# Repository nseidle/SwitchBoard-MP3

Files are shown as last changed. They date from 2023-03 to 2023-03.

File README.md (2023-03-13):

Switchboard MP3 Player
=======

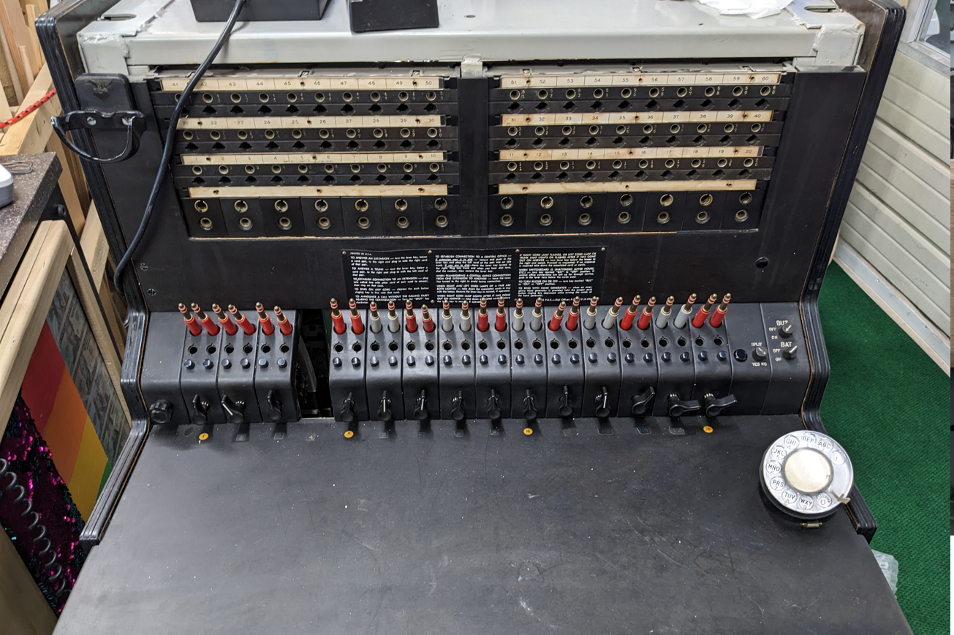
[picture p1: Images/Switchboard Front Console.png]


This project documents the modifications made to a vintage phone switchboard. This is an interactive exhibit at the WOW children's museum in Lafayette. Any of the audio plugs can be inserted into any of the ports in the top console. The light will turn on and one of 74 MP3s will play out the corded phone.

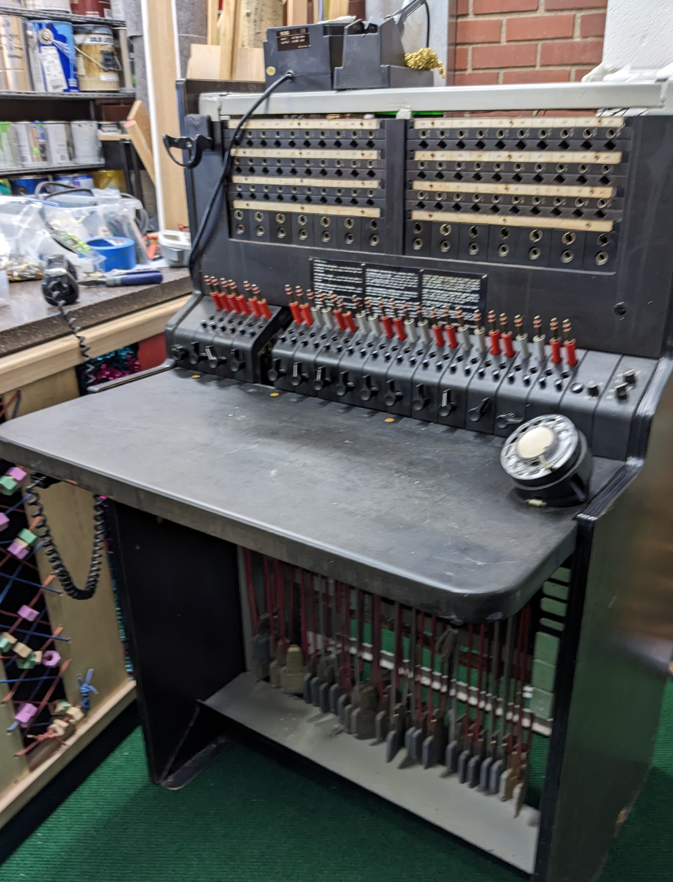
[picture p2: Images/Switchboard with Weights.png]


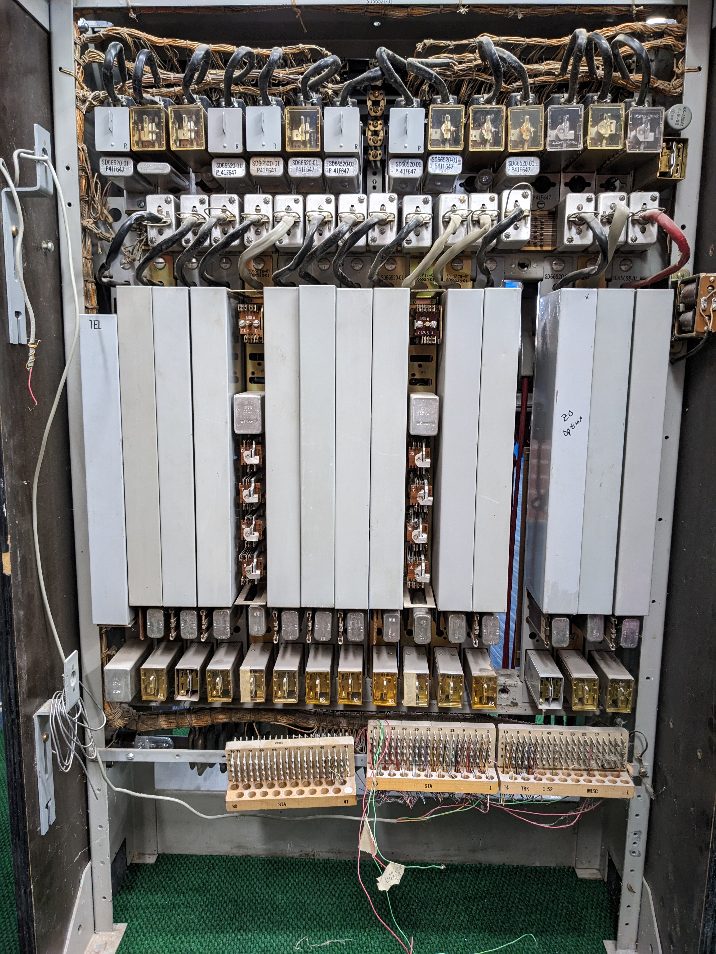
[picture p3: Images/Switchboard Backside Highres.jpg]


It was awesome to work on.

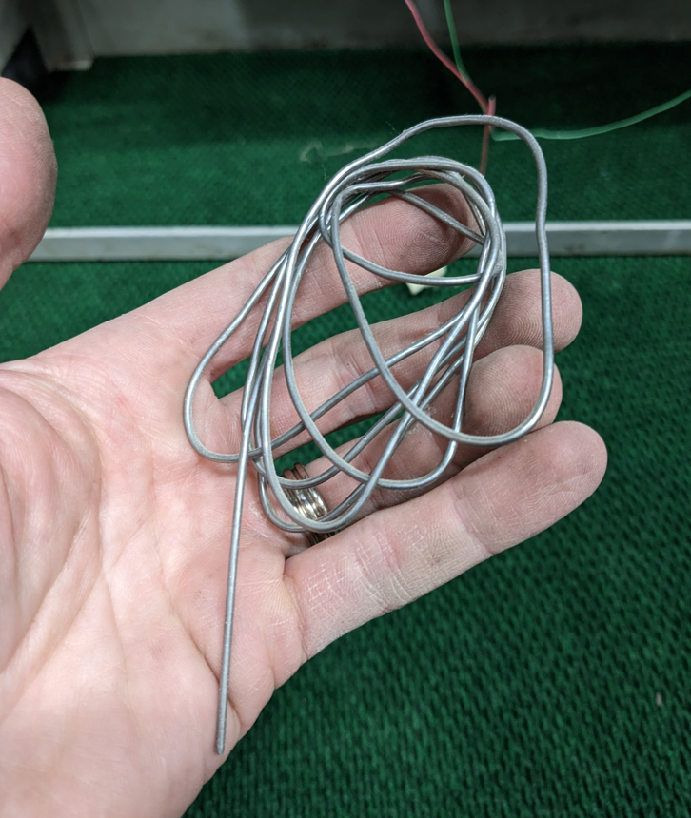
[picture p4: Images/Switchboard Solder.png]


I appreciate the switchboard contained its own solder. From 1956!

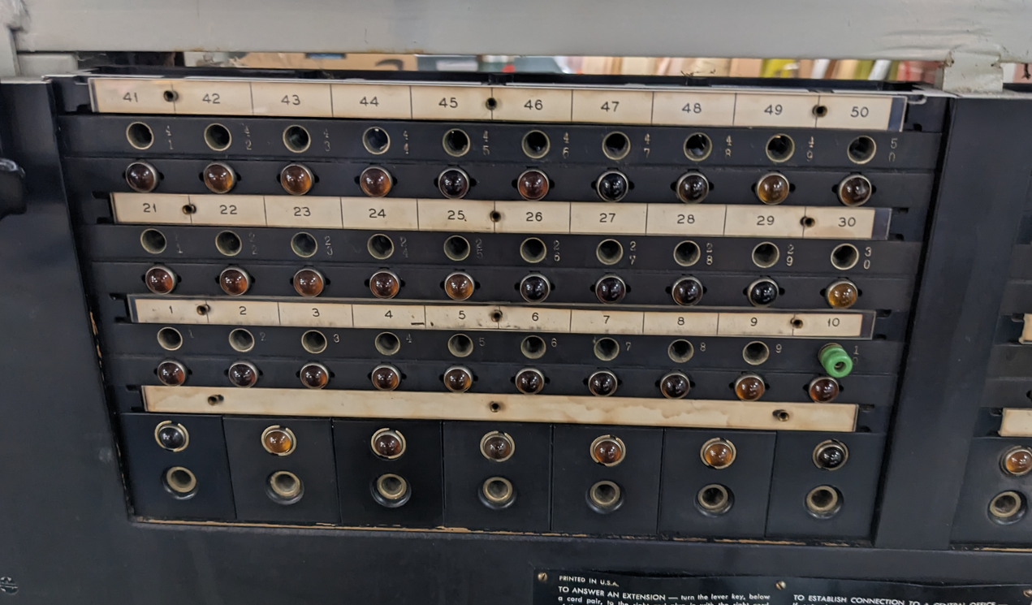
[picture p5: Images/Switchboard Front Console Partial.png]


Above, shows all the original glass lamp covers

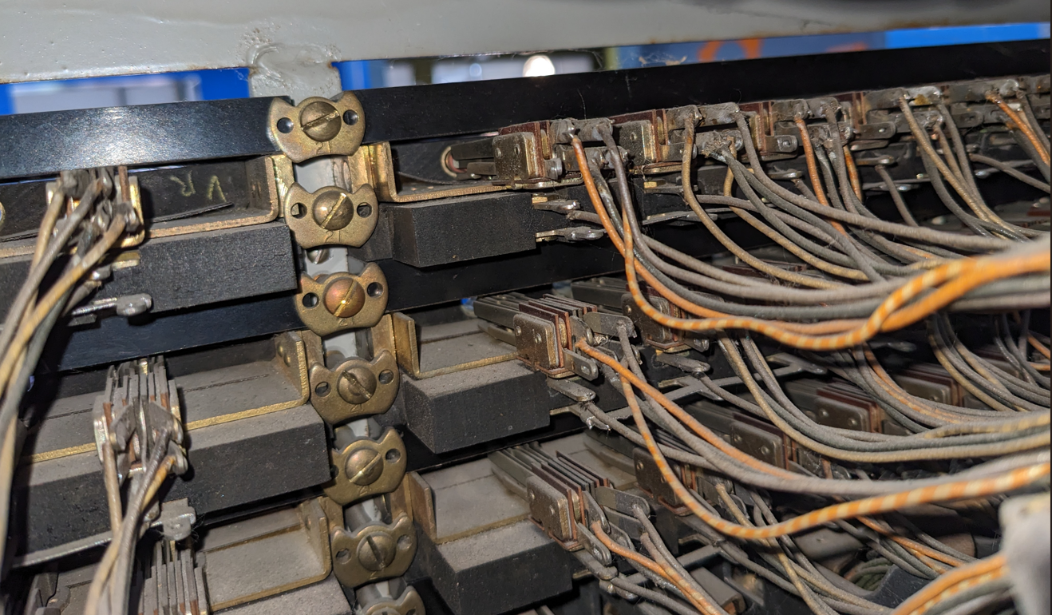
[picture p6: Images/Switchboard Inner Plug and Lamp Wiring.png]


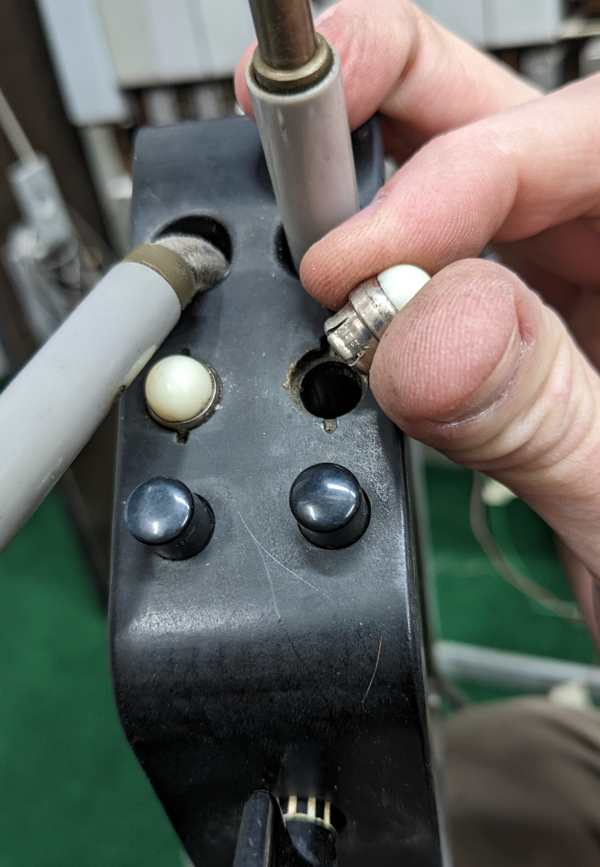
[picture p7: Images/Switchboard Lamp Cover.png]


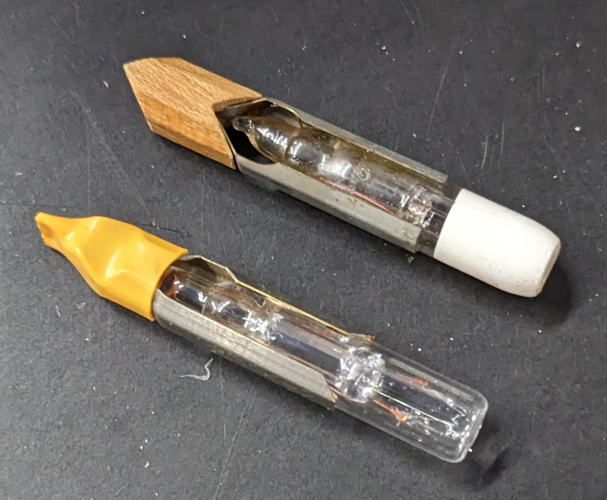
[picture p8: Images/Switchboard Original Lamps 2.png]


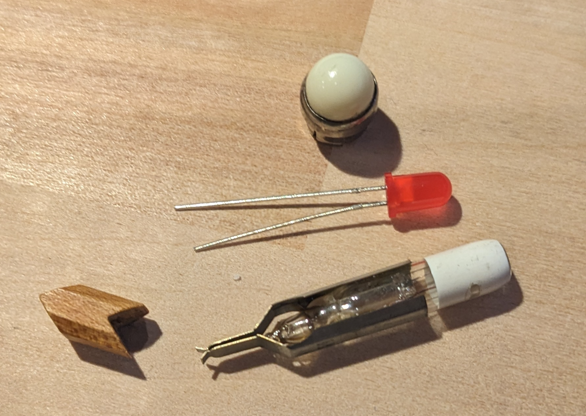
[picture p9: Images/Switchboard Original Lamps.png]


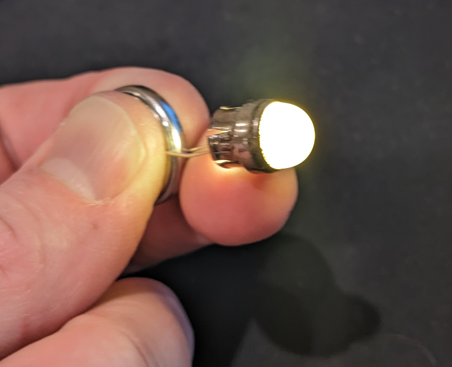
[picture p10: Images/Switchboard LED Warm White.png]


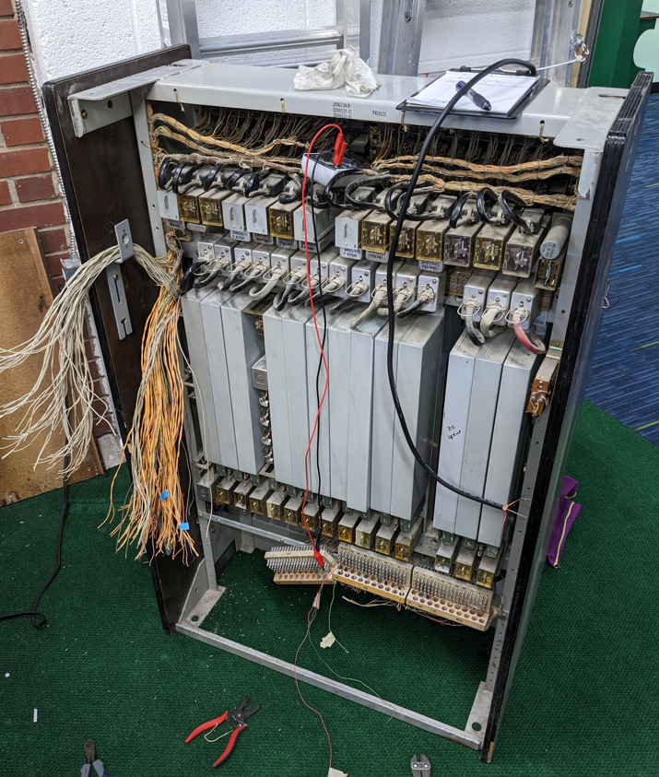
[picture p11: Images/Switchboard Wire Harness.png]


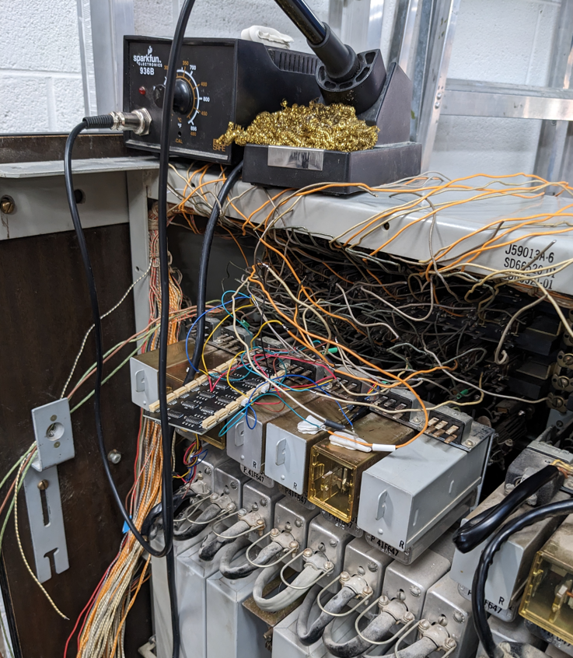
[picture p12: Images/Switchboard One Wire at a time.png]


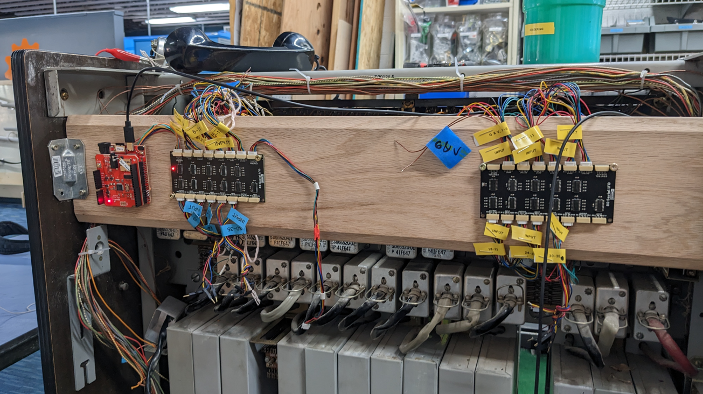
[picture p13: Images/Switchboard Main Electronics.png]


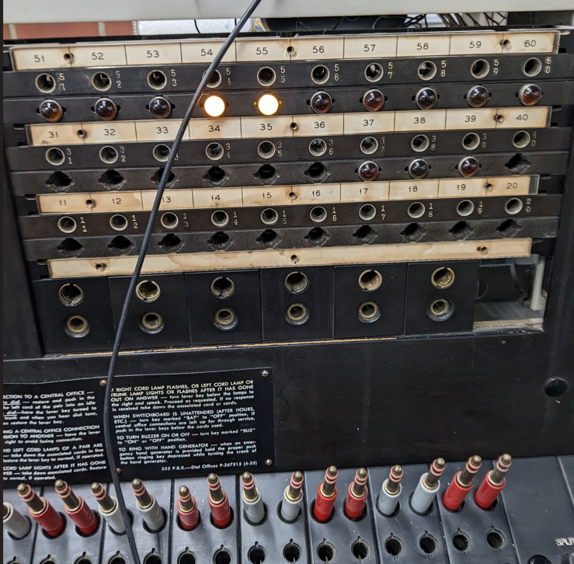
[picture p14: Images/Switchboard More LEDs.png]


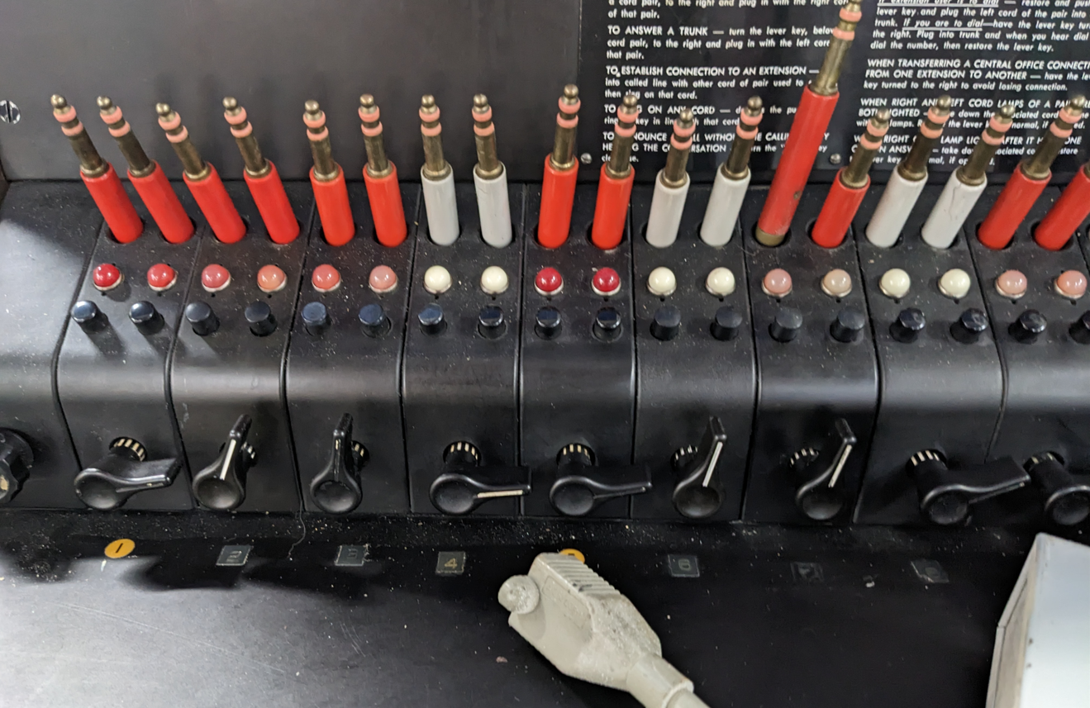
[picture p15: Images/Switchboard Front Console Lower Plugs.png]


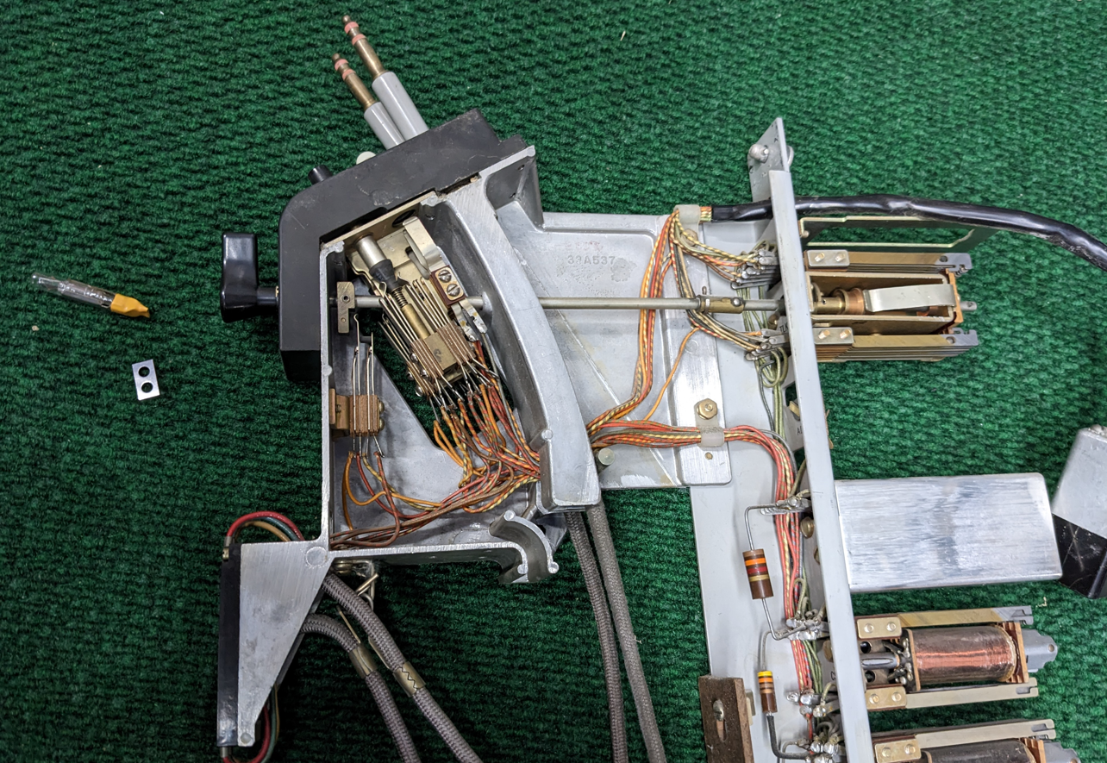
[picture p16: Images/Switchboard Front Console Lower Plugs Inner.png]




[Movie of LEDs](Images/Switchboard%20LEDs.mp4)

Repository Contents
-------------------

* **/firmware** - The code that runs on the ESP32.
* **/hardware** - A custom I/O board capable of 40 inputs and 40 outputs per board, with the ability to chain any number of boards together.

License Information
-------------------

This design is [OSHW](http://www.oshwa.org/definition/) and public domain but you buy me a beer if you use this and we meet someday ([Beerware license](http://en.wikipedia.org/wiki/Beerware)).

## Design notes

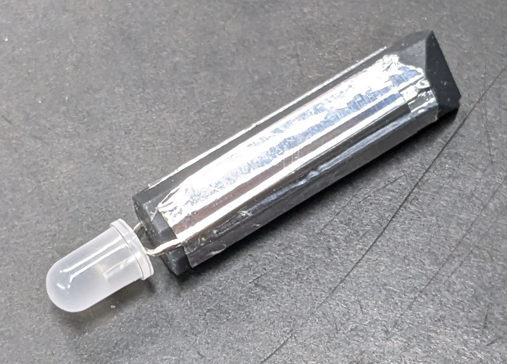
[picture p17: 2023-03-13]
Images/Switchboard LED Replacement.png

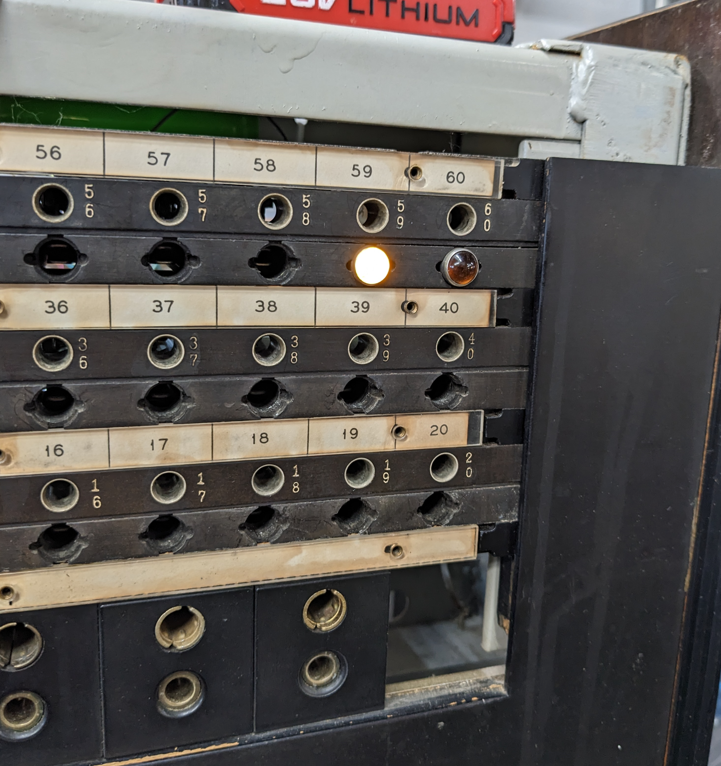
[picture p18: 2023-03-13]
Images/Switchboard Illuminated Light Caps.png

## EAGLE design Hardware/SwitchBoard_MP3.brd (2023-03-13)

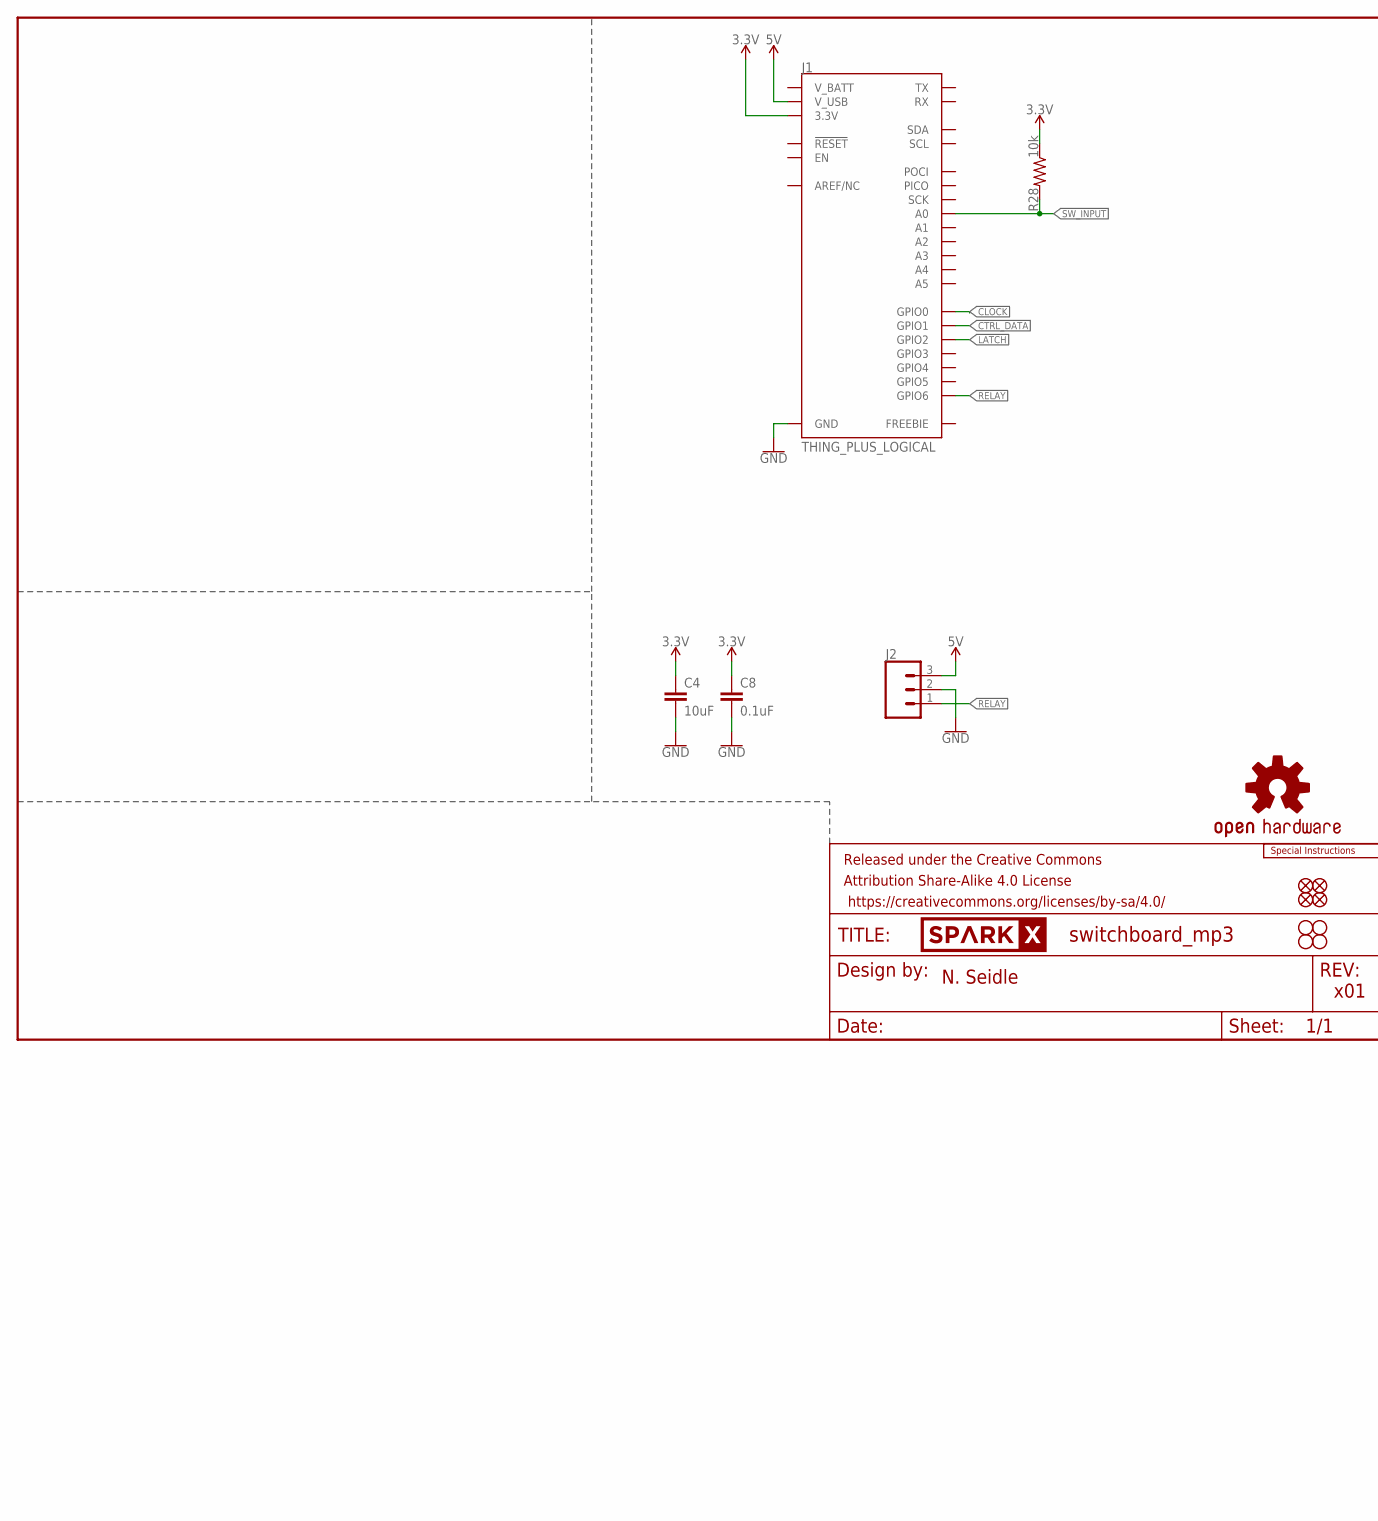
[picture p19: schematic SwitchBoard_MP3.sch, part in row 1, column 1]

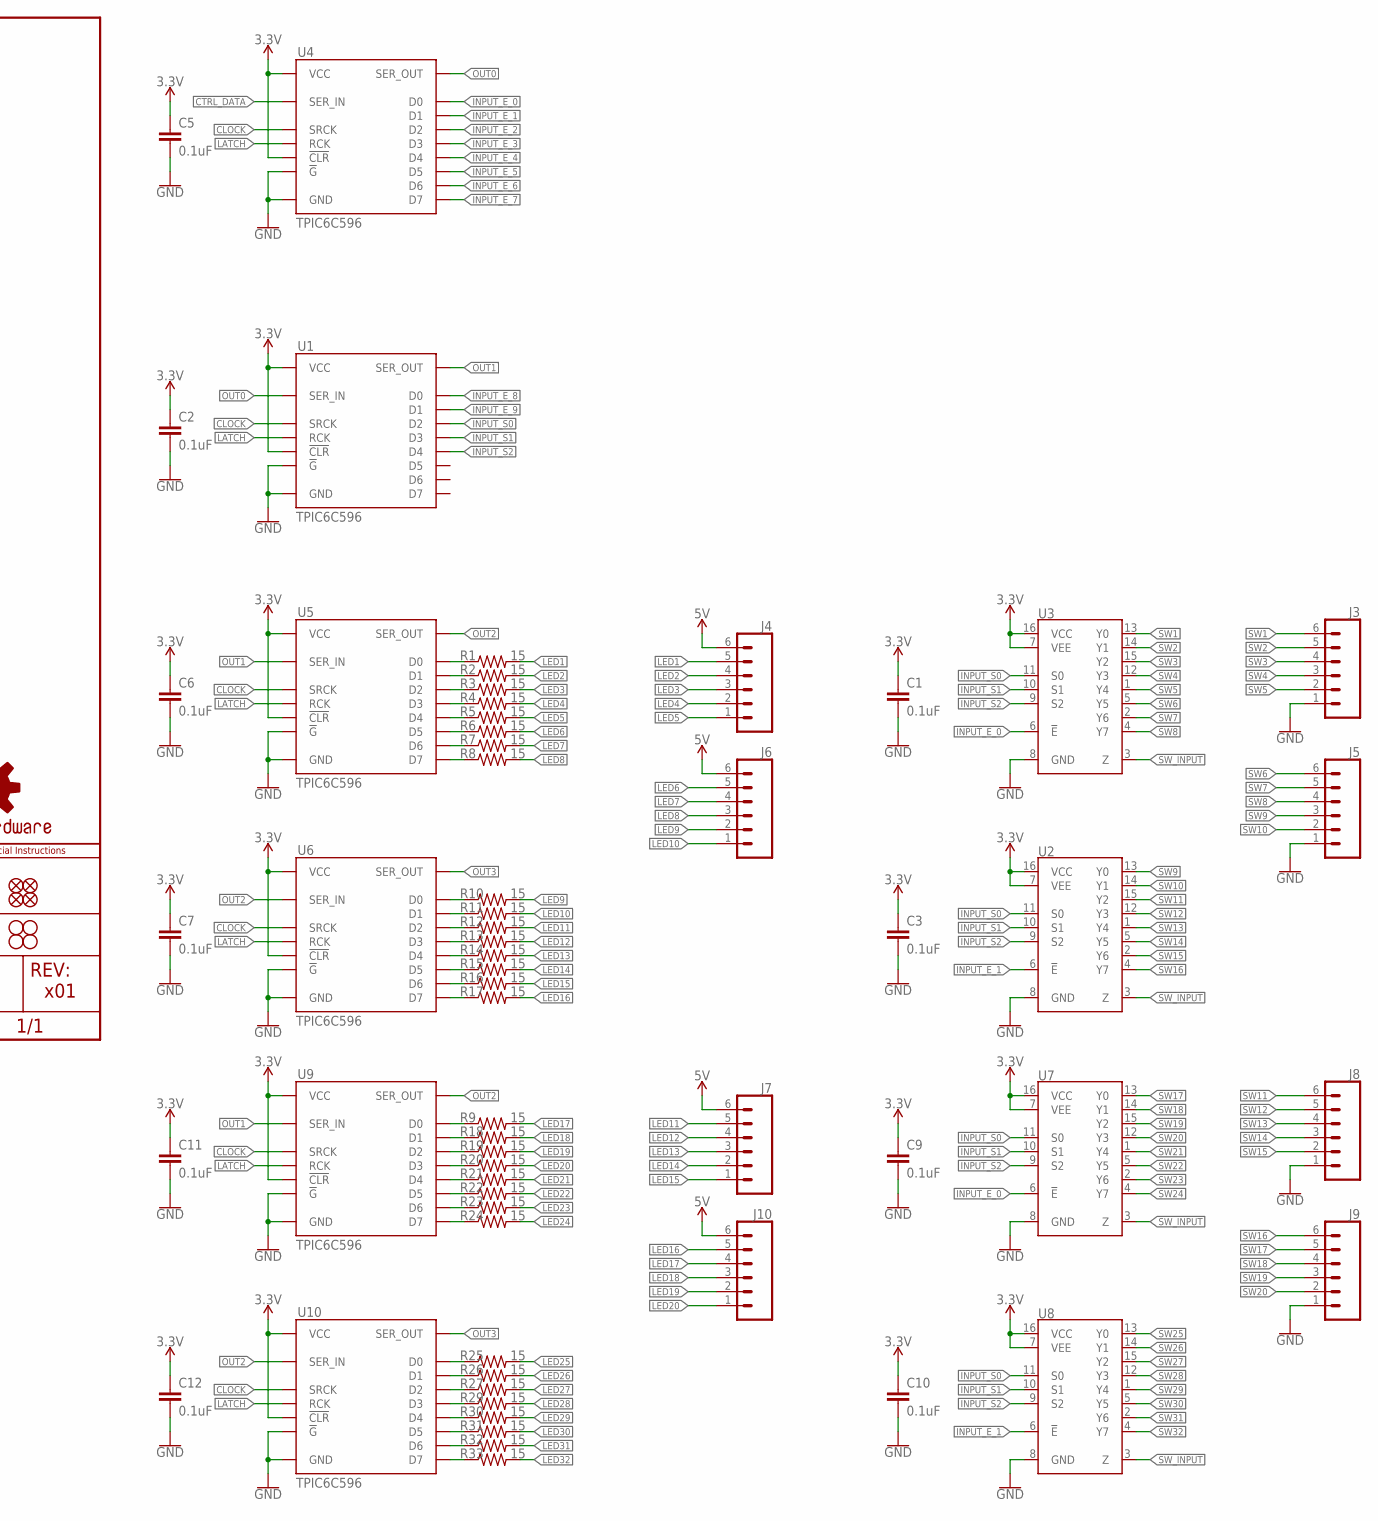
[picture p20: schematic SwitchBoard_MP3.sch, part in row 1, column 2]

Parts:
C1, C2, C3, C5, C6, C7, C8, C9, C10, C11, C12: 0.1uF; 0603
C4: 10uF; 0805
FD1, FD2, FD3, FD4: FIDUCIAL1X2; FIDUCIAL-1X2
FRAME1: FRAME-LETTER; CREATIVE_COMMONS
H1, H2, H3, H4: STAND-OFF
J1: THING_PLUS_LOGICAL; THING_PLUS
J2: CONN_03JST-PTH-NS; JST-3-PTH-NS
J3, J4, J5, J6, J7, J8, J9, J10: CONN_06JST-SMD-LOCKING; JST-6-SMD-1.25MM-LOCKING
LOGO1: SPECIAL_INSTRUCTIONS-ORDERING; ORDERING_INSTRUCTIONS
LOGO2: OSHW-LOGOS; OSHW-LOGO-S
R1, R2, R3, R4, R5, R6, R7, R8, R9, R10, R11, R12, R13, R14, R15, R16, R17, R18, R19, R20, R21, R22, R23, R24, R25, R26, R27, R29, R30, R31, R32, R33: 15; 0603
R28: 10k; 0603
U1, U4, U5, U6, U9, U10: TPIC6C596; SO016
U2, U3, U7, U8: 744051; SO16
U$1: SPARKX-LOGO4; SPARKX-MEDIUM

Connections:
3.3V: C1.1, C2.1, C3.1, C4.1, C5.1, C6.1, C7.1, C8.1, C9.1, C10.1, C11.1, C12.1, J1.27 (3.3V), R28.1, U1.1 (VCC), U1.7 (!CLR), U2.7 (VEE), U2.16 (VCC), U3.7 (VEE), U3.16 (VCC), U4.1 (VCC), U4.7 (!CLR), U5.1 (VCC), U5.7 (!CLR), U6.1 (VCC), U6.7 (!CLR), U7.7 (VEE), U7.16 (VCC), U8.7 (VEE), U8.16 (VCC), U9.1 (VCC), U9.7 (!CLR), U10.1 (VCC), U10.7 (!CLR)
5V: J1.10 (V_USB), J2.3, J4.6, J6.6, J7.6, J10.6
CLOCK: J1.9 (GPIO0), U1.15 (SRCK), U4.15 (SRCK), U5.15 (SRCK), U6.15 (SRCK), U9.15 (SRCK), U10.15 (SRCK)
CTRL_DATA: J1.8 (GPIO1), U4.2 (SER_IN)
GND: C1.2, C2.2, C3.2, C4.2, C5.2, C6.2, C7.2, C8.2, C9.2, C10.2, C11.2, C12.2, J1.25 (GND), J2.2, J3.1, J5.1, J8.1, J9.1, U1.8 (!G), U1.16 (GND), U2.8 (GND), U3.8 (GND), U4.8 (!G), U4.16 (GND), U5.8 (!G), U5.16 (GND), U6.8 (!G), U6.16 (GND), U7.8 (GND), U8.8 (GND), U9.8 (!G), U9.16 (GND), U10.8 (!G), U10.16 (GND)
INPUT_!E!_0: U3.6 (!E!), U4.3 (D0), U7.6 (!E!)
INPUT_!E!_1: U2.6 (!E!), U4.4 (D1), U8.6 (!E!)
INPUT_!E!_2: U4.5 (D2)
INPUT_!E!_3: U4.6 (D3)
INPUT_!E!_4: U4.11 (D4)
INPUT_!E!_5: U4.12 (D5)
INPUT_!E!_6: U4.13 (D6)
INPUT_!E!_7: U4.14 (D7)
INPUT_!E!_8: U1.3 (D0)
INPUT_!E!_9: U1.4 (D1)
INPUT_S0: U1.5 (D2), U2.11 (S0), U3.11 (S0), U7.11 (S0), U8.11 (S0)
INPUT_S1: U1.6 (D3), U2.10 (S1), U3.10 (S1), U7.10 (S1), U8.10 (S1)
INPUT_S2: U1.11 (D4), U2.9 (S2), U3.9 (S2), U7.9 (S2), U8.9 (S2)
LATCH: J1.7 (GPIO2), U1.10 (RCK), U4.10 (RCK), U5.10 (RCK), U6.10 (RCK), U9.10 (RCK), U10.10 (RCK)
LED1: J4.5, R1.2
LED2: J4.4, R2.2
LED3: J4.3, R3.2
LED4: J4.2, R4.2
LED5: J4.1, R5.2
LED6: J6.5, R6.2
LED7: J6.4, R7.2
LED8: J6.3, R8.2
LED9: J6.2, R10.2
LED10: J6.1, R11.2
LED11: J7.5, R12.2
LED12: J7.4, R13.2
LED13: J7.3, R14.2
LED14: J7.2, R15.2
LED15: J7.1, R16.2
LED16: J10.5, R17.2
LED17: J10.4, R9.2
LED18: J10.3, R18.2
LED19: J10.2, R19.2
LED20: J10.1, R20.2
LED21: R21.2
LED22: R22.2
LED23: R23.2
LED24: R24.2
LED25: R25.2
LED26: R26.2
LED27: R27.2
LED28: R29.2
LED29: R30.2
LED30: R31.2
LED31: R32.2
LED32: R33.2
unnamed: R1.1, U5.3 (D0)
unnamed: R2.1, U5.4 (D1)
unnamed: R3.1, U5.5 (D2)
unnamed: R4.1, U5.6 (D3)
unnamed: R5.1, U5.11 (D4)
unnamed: R6.1, U5.12 (D5)
unnamed: R7.1, U5.13 (D6)
unnamed: R8.1, U5.14 (D7)
unnamed: R9.1, U9.3 (D0)
unnamed: R10.1, U6.3 (D0)
unnamed: R11.1, U6.4 (D1)
unnamed: R12.1, U6.5 (D2)
unnamed: R13.1, U6.6 (D3)
unnamed: R14.1, U6.11 (D4)
unnamed: R15.1, U6.12 (D5)
unnamed: R16.1, U6.13 (D6)
unnamed: R17.1, U6.14 (D7)
unnamed: R18.1, U9.4 (D1)
unnamed: R19.1, U9.5 (D2)
unnamed: R20.1, U9.6 (D3)
unnamed: R21.1, U9.11 (D4)
unnamed: R22.1, U9.12 (D5)
unnamed: R23.1, U9.13 (D6)
unnamed: R24.1, U9.14 (D7)
unnamed: R25.1, U10.3 (D0)
unnamed: R26.1, U10.4 (D1)
unnamed: R27.1, U10.5 (D2)
unnamed: R29.1, U10.6 (D3)
unnamed: R30.1, U10.11 (D4)
unnamed: R31.1, U10.12 (D5)
unnamed: R32.1, U10.13 (D6)
unnamed: R33.1, U10.14 (D7)
OUT0: U1.2 (SER_IN), U4.9 (SER_OUT)
OUT1: U1.9 (SER_OUT), U5.2 (SER_IN), U9.2 (SER_IN)
OUT2: U5.9 (SER_OUT), U6.2 (SER_IN), U9.9 (SER_OUT), U10.2 (SER_IN)
OUT3: U6.9 (SER_OUT), U10.9 (SER_OUT)
RELAY: J1.3 (GPIO6), J2.1
SW1: J3.6, U3.13 (Y0)
SW2: J3.5, U3.14 (Y1)
SW3: J3.4, U3.15 (Y2)
SW4: J3.3, U3.12 (Y3)
SW5: J3.2, U3.1 (Y4)
SW6: J5.6, U3.5 (Y5)
SW7: J5.5, U3.2 (Y6)
SW8: J5.4, U3.4 (Y7)
SW9: J5.3, U2.13 (Y0)
SW10: J5.2, U2.14 (Y1)
SW11: J8.6, U2.15 (Y2)
SW12: J8.5, U2.12 (Y3)
SW13: J8.4, U2.1 (Y4)
SW14: J8.3, U2.5 (Y5)
SW15: J8.2, U2.2 (Y6)
SW16: J9.6, U2.4 (Y7)
SW17: J9.5, U7.13 (Y0)
SW18: J9.4, U7.14 (Y1)
SW19: J9.3, U7.15 (Y2)
SW20: J9.2, U7.12 (Y3)
SW21: U7.1 (Y4)
SW22: U7.5 (Y5)
SW23: U7.2 (Y6)
SW24: U7.4 (Y7)
SW25: U8.13 (Y0)
SW26: U8.14 (Y1)
SW27: U8.15 (Y2)
SW28: U8.12 (Y3)
SW29: U8.1 (Y4)
SW30: U8.5 (Y5)
SW31: U8.2 (Y6)
SW32: U8.4 (Y7)
SW_INPUT: J1.24 (A0), R28.2, U2.3 (Z), U3.3 (Z), U7.3 (Z), U8.3 (Z)

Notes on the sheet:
x01
N. Seidle

Board: 4 copper layers, 88 parts (2 on the bottom side), 89 nets, no tracks yet.

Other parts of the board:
U$2: 5_4_3_2_1_V0
U$3, U$7, U$11, U$12: LAMP0
U$4, U$6, U$8, U$9, U$10: SWITCH0
U$5: G_5_4_3_2_10

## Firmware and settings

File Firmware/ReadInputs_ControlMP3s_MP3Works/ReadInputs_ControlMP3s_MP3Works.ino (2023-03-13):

/*
  Control 80 LEDs and 80 inputs through two boards
  If switch is closed, play associated MP3
  By: Nathan Seidle
  SparkFun Electronics
  Date: February 22, 2023
  License: MIT. See license file for more information but you can basically do whatever you want with this code.

  We detect the insertion of cables into the various ports on an old telephone switch board. If a cable is inserted into
  port 1, 1.mp3 is played and the associated LED is lit up. The MP3 will continue to play until the cable is pulled out,
  or a higher number port is plugged.

  If no cables are plugged in, we play 0.mp3 on a loop and light up the LEDs in a chasing pattern.

  The board closest to the ESP32 is the primary board. The numbers on the primary board
  reflect reality (input 1 = input 1). On the 2nd board, the numbers are 1 + 40. Input 1 is
  input 41.
*/

//Pins
//-=-=-=-=-=-=-=-=-=-=-=-=-=-=-=-=-=-=-=-=-=-=-=-=-=-=-=-=-=-=-=-=-=-=-=-=-=-=-=-=-=-=-=-=-=-=-=-=-
const int DATA = 4; //S
const int CLOCK = 16; //C
const int LATCH = 14; //L
const int SWITCH = 32; //I Avoid 36, 39, etc input only as they do not have pull-ups

//int pin_sdcs = 9;
int pin_sdcs = 5; //Onboard socket
//-=-=-=-=-=-=-=-=-=-=-=-=-=-=-=-=-=-=-=-=-=-=-=-=-=-=-=-=-=-=-=-=-=-=-=-=-=-=-=-=-=-=-=-=-=-=-=-=-

uint8_t ledStateA[5];
uint8_t ledStateB[5];
// Byte 0 - Byte 1 - Byte 2 ... Byte n
// 76543210
// LED87654321 LED16151413121110 LED2423222120191817

uint8_t switchControlA = 0;
uint8_t switchControlB = 0;
// 8 bits
// INPUT E0 to E4, S0 to S2

uint8_t switchStateA[5];
uint8_t switchStateB[5];
// Byte 0 - Byte 1 - Byte 2 ... Byte n
// 76543210
// SW87654321 LED16151413121110 LED2423222120191817

#define BYTE_TO_BINARY_PATTERN "%c%c%c%c%c%c%c%c"
#define BYTE_TO_BINARY(byte)  \
  (byte & 0x80 ? '1' : '0'), \
  (byte & 0x40 ? '1' : '0'), \
  (byte & 0x20 ? '1' : '0'), \
  (byte & 0x10 ? '1' : '0'), \
  (byte & 0x08 ? '1' : '0'), \
  (byte & 0x04 ? '1' : '0'), \
  (byte & 0x02 ? '1' : '0'), \
  (byte & 0x01 ? '1' : '0')

//#include <avr/wdt.h> //We need watch dog for this program

//sdFat for SD card
//-=-=-=-=-=-=-=-=-=-=-=-=-=-=-=-=-=-=-=-=-=-=-=-=-=-=-=-=-=-=-=-=-=-=-=-=-=-=-=-=-=-=-=-=-=-=-=-=-
#include <SdFat.h>         // SDFat Library
SdFat sd; // Create object to handle SD functions
//-=-=-=-=-=-=-=-=-=-=-=-=-=-=-=-=-=-=-=-=-=-=-=-=-=-=-=-=-=-=-=-=-=-=-=-=-=-=-=-=-=-=-=-=-=-=-=-=-

//MP3
//-=-=-=-=-=-=-=-=-=-=-=-=-=-=-=-=-=-=-=-=-=-=-=-=-=-=-=-=-=-=-=-=-=-=-=-=-=-=-=-=-=-=-=-=-=-=-=-=-
#include <VS1053.h> //https://github.com/baldram/ESP_VS1053_Library

//You must cut the GPIO and MIDI traces on the shield
#define VS1053_CS     17
#define VS1053_DCS    25
#define VS1053_DREQ   4

VS1053 player(VS1053_CS, VS1053_DCS, VS1053_DREQ);

#define VOLUME  90 // volume level 0-100

int previousTrack1 = 1; //Used to prevent the playing of sounds twice in a row
int previousTrack2 = 2;

boolean playerStopped = false; //Goes true when track has ended and we need to play SILENCE.MP3

//-=-=-=-=-=-=-=-=-=-=-=-=-=-=-=-=-=-=-=-=-=-=-=-=-=-=-=-=-=-=-=-=-=-=-=-=-=-=-=-=-=-=-=-=-=-=-=-=-

SdFile trackFile;

void setup()
{
  Serial.begin(115200);
  delay(250);

  Serial.println("Hello!");

  SPI.begin();

  //  pinMode(CLOCK, OUTPUT);
  //  pinMode(LATCH, OUTPUT);
  //  pinMode(DATA, OUTPUT);
  //  pinMode(SWITCH, INPUT_PULLUP);

  pinMode(26, OUTPUT);
  digitalWrite(26, HIGH);

  //  digitalWrite(CLOCK, LOW);
  //  digitalWrite(LATCH, LOW);
  //  digitalWrite(DATA, LOW);

  initSD();  // Initialize the SD card
  //  initMP3Player(); // Initialize the MP3 Shield

  //char trackName[40] = "TRACK001.WAV";
  char trackName[40] = "T001.MP3";
  if (trackFile.open(trackName, O_READ) == false)
  {
    Serial.println("Failed to open file");
    while (1);
  }


  player.begin();
  player.switchToMp3Mode(); // optional, some boards require this
  player.setVolume(VOLUME);




  //printMenu();

  //playRandomTrack();

  //    switchControlA = 0b11100001; //Select channel Y0, on register 0
  //    sendFrame();
  //
  //    delay(50);
  //    while (Serial.available()) Serial.read();
  //
  //    while (Serial.available() == 0)
  //    {
  //      int value = analogRead(SWITCH);
  //      Serial.printf("switch: %d\n\r", value);
  //      //    if (digitalRead(SWITCH) == HIGH)
  //      //      Serial.println("High");
  //      //    else
  //      //      Serial.println("Low");
  //      delay(500);
  //    }

  //  delay(50);
  //  while (Serial.available()) Serial.read();
  //
  //  while (Serial.available() == 0)
  //  {
  //    readSwitches();
  //
  //    for(int x = 1 ; x <= 40 ; x++)
  //    {
  //      if(checkSwitch(x) == false)
  //      {
  //        Serial.printf("switch %d\n\r", x);
  //      }
  //    }
  //
  //    delay(100);
  //  }

  player.startSong();
}

void loop()
{
  if (player.data_request() == true)
  {
    uint8_t mp3DataBuffer[32];

    // Go out to SD card and try reading some number of bytes
    int bytesToPlay = trackFile.read(mp3DataBuffer, sizeof(mp3DataBuffer));
    if (bytesToPlay <= 0)
    {
      Serial.println("Stop file");

      //No data left in file
      player.stopSong();
      trackFile.close(); // Close out this track
    }
    else
    {
      Serial.printf("Play %d\r\n", bytesToPlay);
      player.playChunk(mp3DataBuffer, bytesToPlay);
    }
  }

  if (Serial.available())
  {
    byte incoming = Serial.read();
    if (incoming == 'r')
    {
      ESP.restart();
    }
    else if (incoming == 's')
    {
      unsigned long startTime = micros();
      sendFrame();
      unsigned long stopTime = micros(); //26us

      Serial.printf("Time for sendFrame: %d\r\n", stopTime - startTime);
    }
    else if (incoming == 'b')
    {
      unsigned long startTime = micros();
      readSwitches();
      unsigned long stopTime = micros(); //687us

      Serial.printf("Time for readSwitches: %d\r\n", stopTime - startTime);

      if (checkSwitch(3) == LOW)
        Serial.println("Button 3 low");
      else
        Serial.println("Button 3 high");
    }
    else if (incoming == 'w')
    {
      Serial.println("Checking switches");

      delay(50);
      while (Serial.available()) Serial.read();

      while (Serial.available() == 0)
      {
        unsigned long startTime = micros();

        readSwitches();
        unsigned long stopTime = micros(); //26us

        Serial.printf("Time for readSwitches: %d\r\n", stopTime - startTime);

        for (int x = 1 ; x <= 80 ; x++)
        {
          if (checkSwitch(x) == false)
            Serial.printf("Switch %d\n\r", x);
        }

        Serial.printf("switchState Array: 0x%02X %02X %02X %02X %02X %02X %02X %02X %02X %02X",
                      switchStateA[4], switchStateA[3], switchStateA[2], switchStateA[1], switchStateA[0],
                      switchStateB[4], switchStateB[3], switchStateB[2], switchStateB[1], switchStateB[0]
                     );
        Serial.println();

        delay(100);
      }
    }

    else if (incoming == '1')
    {
      delay(50);
      while (Serial.available()) Serial.read();

      Serial.println("Blinking");

      while (Serial.available() == 0)
      {
        setLED(1, HIGH);
        setLED(2, LOW);

        Serial.printf("LED Array: 0x%02X %02X %02X %02X %02X", ledStateA[4], ledStateA[3], ledStateA[2], ledStateA[1], ledStateA[0]);
        Serial.println();
        sendFrame();
        delay(2000);

        setLED(1, LOW);
        setLED(2, HIGH);

        Serial.printf("LED Array: 0x%02X %02X %02X %02X %02X", ledStateA[4], ledStateA[3], ledStateA[2], ledStateA[1], ledStateA[0]);
        Serial.println();
        sendFrame();
        delay(2000);
      }
    }

#define LED_COUNT 80

    else if (incoming == '2')
    {
      Serial.println("LED display 1");

      //Make the LEDs chase each other with a gap between them
      //Start on LED 1 and proceed

#define LED_GAP 5 //Number of dark LEDs between lit LEDs

      int shifts = 0;

      delay(50);
      while (Serial.available()) Serial.read();

      int startingLED = 1;
      int toLight = 1;
      while (Serial.available() == 0)
      {
        //Clear the LED arrays
        for (int x = 0 ; x < 5 ; x++)
        {
          ledStateA[x] = 0;
          ledStateB[x] = 0;
        }

        //Set the appropriate LEDs
        int litLEDs = 0;
        for (int x = 0 ; x < LED_COUNT ; x++)
        {
          if ( (x % startingLED) == 0)
          {
            setLED(x, HIGH);

            litLEDs++;
            if (litLEDs == toLight) break;
          }
        }

        //Move to next starting spot
        startingLED++;
        startingLED %= LED_GAP; //Wrap

        //Make sure we don't get too large
        toLight++;
        toLight %= LED_COUNT;

        //Display output
        Serial.printf("LED Array: ");

        printBinary(ledStateB[4]);
        printBinary(ledStateB[3]);
        printBinary(ledStateB[2]);
        printBinary(ledStateB[1]);
        printBinary(ledStateB[0]);

        Serial.println();

        delay(2000);

        //        for (int ledByte = 0 ; ledByte < 5 ; ledByte++)
        //        {
        //          //Check if the highest bit is set, then move to next byte
        //          if (ledStateA[ledByte] & 0b10000000)
        //          {
        //            if (ledBytes < 5)
        //              ledStatA[ledByte + 1] |= 0b1; //Move bit to next byte up
        //          }
        //
        //          //Shift this byte by one
        //          shifts++;
        //          ledStateA[ledByte] <<= 1;
        //
        //          //Add a bit to the starting byte when needed
        //          if (ledByte == 0 && shifts == LED_GAP)
        //          {
        //            shifts = 0;
        //            ledStateA[0] |= 0b1;
        //          }
        //        }
      }

    }
  }
}

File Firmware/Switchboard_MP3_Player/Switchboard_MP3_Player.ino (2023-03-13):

/*
  Control 80 LEDs and 80 inputs through two boards
  If switch is closed, play associated MP3
  By: Nathan Seidle
  SparkFun Electronics
  Date: February 22, 2023
  License: MIT. See license file for more information but you can basically do whatever you want with this code.

  We detect the insertion of cables into the various ports on an old telephone switch board. If a cable is inserted into
  port 1, T001.mp3 is played and the associated LED is lit up. The MP3 will continue to play until the cable is pulled out,
  or a higher number port is plugged.

  If no cables are plugged in, we play T000.mp3 on a loop and light up the LEDs in a chasing pattern.

  The board closest to the ESP32 is the primary board. The numbers on the primary board
  reflect reality (input 1 = input 1). On the 2nd board, the numbers are 1 + 40, i.e. input 1 is
  input 41.

  A array of 5 bytes can read the switches (switchState) and LEDs (ledState) from a given I/O board.
  The closest board uses arrays 'B', the 2nd board uses arrays 'A'.

  Hardware:

  The plugs are 1/4" and are inserted into a jack from the front. The jack has two paddles that are NC
  connected to ground. When inserted, the paddles are separated, and the system sees a high input.

  The LEDs are bussed with all 3.3V on the high side, and individually sunk through sink drivers. The
  LEDs are inserted into the front panel with long leg oriented towards the top of the hole.
  Reasoning: Long leg is on the round side, or negative.
*/

const int numberOfPlugs = 80;
const int numberOfLEDs = 80;

//Pins
//-=-=-=-=-=-=-=-=-=-=-=-=-=-=-=-=-=-=-=-=-=-=-=-=-=-=-=-=-=-=-=-=-=-=-=-=-=-=-=-=-=-=-=-=-=-=-=-=-
const int DATA = 13; //S
const int CLOCK = 16; //C
const int LATCH = 14; //L
const int SWITCH = 32; //I Avoid 36, 39, etc input only as they do not have pull-ups

//int pin_sdcs = 9;
int pin_sdcs = 5; //Onboard SD socket

int pin_mp3Reset = 26;
//-=-=-=-=-=-=-=-=-=-=-=-=-=-=-=-=-=-=-=-=-=-=-=-=-=-=-=-=-=-=-=-=-=-=-=-=-=-=-=-=-=-=-=-=-=-=-=-=-

#include "settings.h"

//Preferences for storing settings
//-=-=-=-=-=-=-=-=-=-=-=-=-=-=-=-=-=-=-=-=-=-=-=-=-=-=-=-=-=-=-=-=-
#include <Preferences.h>
Preferences systemSettings;
//-=-=-=-=-=-=-=-=-=-=-=-=-=-=-=-=-=-=-=-=-=-=-=-=-=-=-=-=-=-=-=-=-

//sdFat for SD card
//-=-=-=-=-=-=-=-=-=-=-=-=-=-=-=-=-=-=-=-=-=-=-=-=-=-=-=-=-=-=-=-=-=-=-=-=-=-=-=-=-=-=-=-=-=-=-=-=-
#include <SdFat.h>         // SDFat Library
SdFat sd; // Create object to handle SD functions

SdFile trackFile; //Global variable pointing at a given track
//-=-=-=-=-=-=-=-=-=-=-=-=-=-=-=-=-=-=-=-=-=-=-=-=-=-=-=-=-=-=-=-=-=-=-=-=-=-=-=-=-=-=-=-=-=-=-=-=-

//MP3
//-=-=-=-=-=-=-=-=-=-=-=-=-=-=-=-=-=-=-=-=-=-=-=-=-=-=-=-=-=-=-=-=-=-=-=-=-=-=-=-=-=-=-=-=-=-=-=-=-
#include <VS1053.h> //https://github.com/baldram/ESP_VS1053_Library

//You must cut the GPIO and MIDI traces on the shield
#define VS1053_CS     17
#define VS1053_DCS    25
#define VS1053_DREQ   4

VS1053 player(VS1053_CS, VS1053_DCS, VS1053_DREQ);

int previousTrack1 = 1; //Used to prevent the playing of sounds twice in a row
int previousTrack2 = 2;

//-=-=-=-=-=-=-=-=-=-=-=-=-=-=-=-=-=-=-=-=-=-=-=-=-=-=-=-=-=-=-=-=-=-=-=-=-=-=-=-=-=-=-=-=-=-=-=-=-

//Global variables
//-=-=-=-=-=-=-=-=-=-=-=-=-=-=-=-=-=-=-=-=-=-=-=-=-=-=-=-=-=-=-=-=-=-=-=-=-=-=-=-=-=-=-=-=-=-=-=-=-
uint8_t ledStateA[5]; //The higher numbered LEDs 41-80
uint8_t ledStateB[5];
uint8_t ledStateAReality[5]; //The higher numbered LEDs 41-80
uint8_t ledStateBReality[5]; //Loader LEDs 1-40
uint8_t ledTransform[80 + 1]; //Extra because we call the LEDs '1' to '80'
// Byte 0 - Byte 1 - Byte 2 ... Byte n
// 76543210
// LED87654321 LED16151413121110 LED2423222120191817

int leaderLED = 1; //Used during the screen saver to control the front LED

uint8_t switchControlA = 0;
uint8_t switchControlB = 0;
// 8 bits
// INPUT E0 to E4, S0 to S2

uint8_t switchStateA[5]; //The higher numbered switches 41-80
uint8_t switchStateB[5];
uint8_t switchStateAReality[5]; //These are loaded after the transform is applied
uint8_t switchStateBReality[5];
uint8_t switchTransform[80 + 1];
//switchTransform[10] = 61 means that the plug labeled '10' on the front of the switchboard (the user number) is connected to input 61 (Board A, pin 21) on the electronics

// Byte 0 - Byte 1 - Byte 2 ... Byte n
// 76543210
// SW87654321 LED16151413121110 LED2423222120191817

#define BYTE_TO_BINARY_PATTERN "%c%c%c%c%c%c%c%c"
#define BYTE_TO_BINARY(byte)  \
  (byte & 0x80 ? '1' : '0'), \
  (byte & 0x40 ? '1' : '0'), \
  (byte & 0x20 ? '1' : '0'), \
  (byte & 0x10 ? '1' : '0'), \
  (byte & 0x08 ? '1' : '0'), \
  (byte & 0x04 ? '1' : '0'), \
  (byte & 0x02 ? '1' : '0'), \
  (byte & 0x01 ? '1' : '0')

int ledGap = 10; //Number of LEDs off between lit LEDs during screen saver

int lastPlug = 0; //Remember the switch we're playing so that we don't keep starting the MP3

unsigned long lastInteraction = 0; //Used to turn on screen saver when no interaction occurs

bool isPlaying = false; //Tracks when we start/stop a track

bool screenSaverRunning = false; //Cause LEDs to chase if no interactions are detected
unsigned long lastScreenSaverUpdate = 0; //Used to prevent the screen saver from running too fast
int ledDirection = 1;
//-=-=-=-=-=-=-=-=-=-=-=-=-=-=-=-=-=-=-=-=-=-=-=-=-=-=-=-=-=-=-=-=-=-=-=-=-=-=-=-=-=-=-=-=-=-=-=-=-

void setup()
{
  Serial.begin(115200);
  delay(250);

  Serial.println("Switchboard MP3 Player");

  pinMode(CLOCK, OUTPUT);
  pinMode(LATCH, OUTPUT);
  pinMode(DATA, OUTPUT);
  pinMode(SWITCH, INPUT_PULLUP);

  digitalWrite(CLOCK, LOW);
  digitalWrite(LATCH, LOW);
  digitalWrite(DATA, LOW);

  //Before anything, turn off LEDs
  ledOff(); //By default, the LEDs are activated. We don't want that much current.
  sendFrame(); //Push data to the LEDs

  systemSettings.begin("settings"); //Start the preferences library, working within a namespace called settings
  loadSettings();

  initSD(); //Initialize the SD card
  initMP3Player(); //Initialize the MP3 Shield

  loadRealityArrayLEDs(); //Get transform from NVM
  loadRealityArraySwitches(); //Get transform from NVM

  printMainMenu();

  //blinkTest();
  //switchTest();
}

void loop()
{
  updateBoard(); //If a plug has been inserted, update LEDs and play MP3s. Calls readSwitches().

  updateMP3(); //Feed MP3 IC with file data as needed

  if (Serial.available())
    menuMain();
}
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

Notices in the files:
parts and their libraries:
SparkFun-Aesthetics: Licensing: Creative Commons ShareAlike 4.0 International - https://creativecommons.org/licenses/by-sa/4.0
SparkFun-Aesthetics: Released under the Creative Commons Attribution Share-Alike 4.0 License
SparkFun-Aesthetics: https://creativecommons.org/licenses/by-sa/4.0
